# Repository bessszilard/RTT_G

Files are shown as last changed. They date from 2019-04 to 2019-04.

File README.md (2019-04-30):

# RTT_G
## The Autonomous Sign Detector and Object Tracker Robot

*Keywords: differential drive robot, real-time image processing, GUI, Arduino, PCB design, motor control.*

The project includes the construction of a robot with differential drive, itsʼ control mechanism and machine vision based guidance. The robot is controlled by an ATmega2560 microcontroller on an Arduino development board. Itsʼ structure also contains the following elements: sensor-electronics, two DC motors, two accumulators, one servo motor, vision system with active illumination and one Bluetooth module. A proprietary interface card connects the microcontroller with the sensors and the interveners.
The strategic level guidance is accomplished with an application running on PC based architecture. The PC and the robot communicate with each other via Bluetooth. The robot can work in two modes: first one is the manual control mode, the second one is the autonomous mode.
First program is the manually operated mode, in which the user can guide the robot using the PCʼs keyboard. The second program implements autonomous guidance. In this mode, PC controls the robot based on the result of processing a video feed from a mobile phone mounted onto the robot. Image processing is performed on the PC using Emgu CV which is based on the OpenCV libraries.

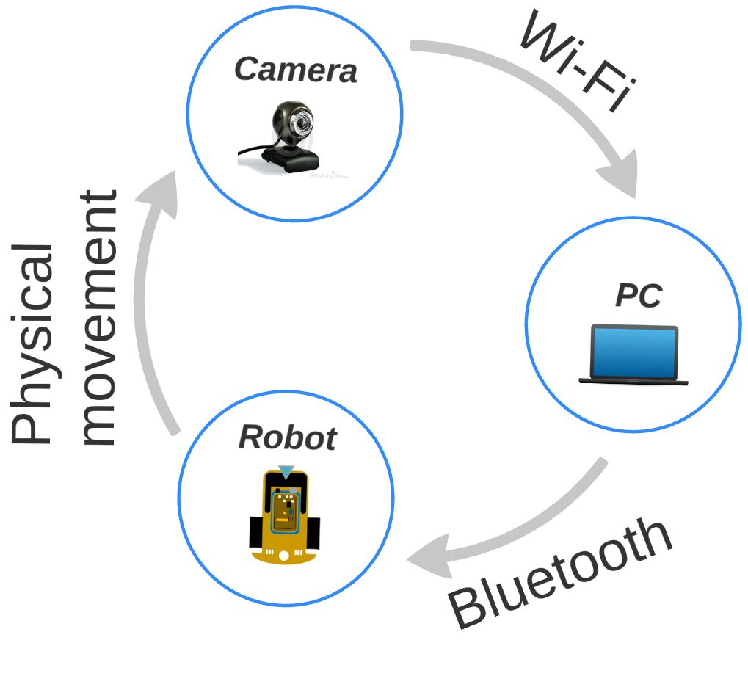
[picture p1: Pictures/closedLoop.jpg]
Closed loop control Title


https://www.youtube.com/watch?v=aYvZUBr8wPQ

## Installing Arduino IDE
* [Windows install](https://www.arduino.cc/en/guide/windows)
* [Linux](https://www.arduino.cc/en/guide/linux)
* [MAC](https://www.dummies.com/computers/arduino/how-to-install-arduino-for-mac-os-x/)

## Arduino projects
* R_TTG_IMG_Proc_9_Serial - Robot is controlled with a Machine Vision program
* R_TTG_Timers_Encoder_test_PID_4 - Robot is controlled with keyboard

## License
MIT License

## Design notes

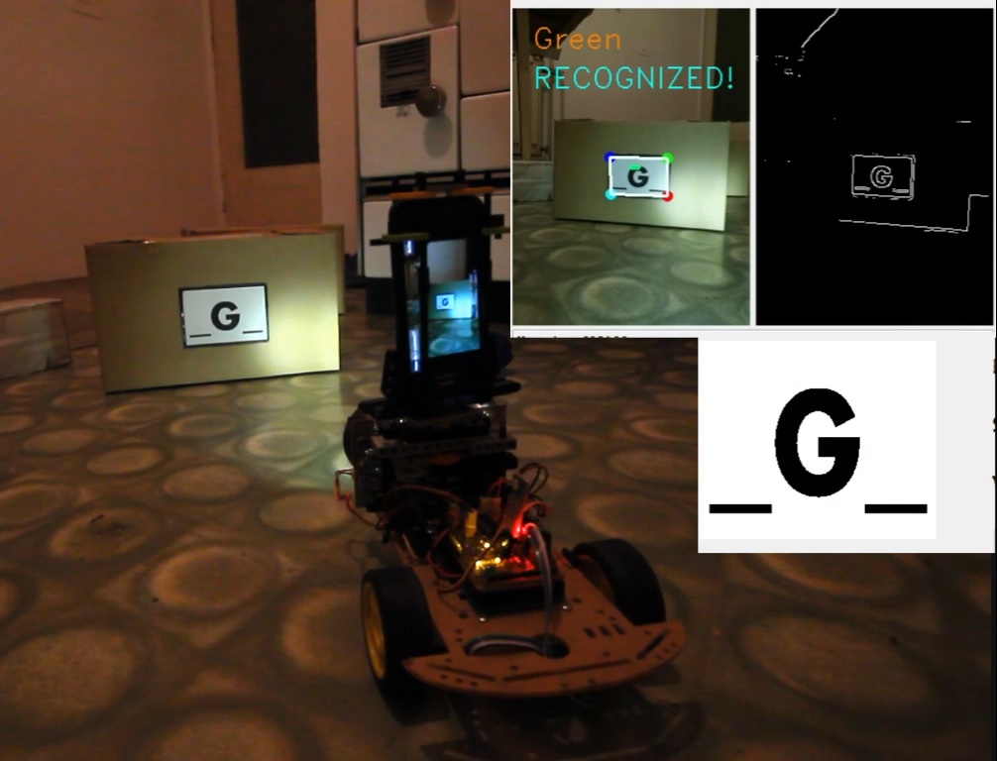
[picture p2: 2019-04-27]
Pictures/Sign_detection2.jpg

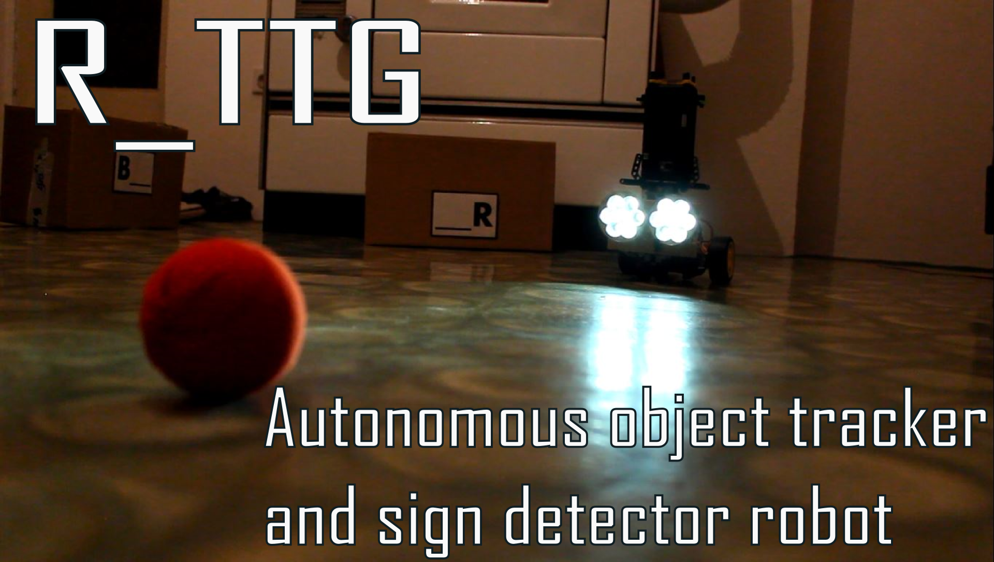
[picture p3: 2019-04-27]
Pictures/cover_photo.jpg.png

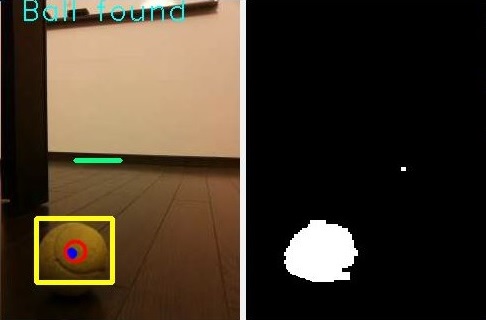
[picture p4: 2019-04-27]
Pictures/Ball_Found.jpg

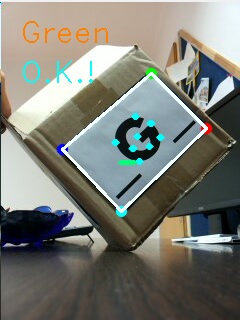
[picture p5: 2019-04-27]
Pictures/perspektiv_korrekcio_eredeti.jpg

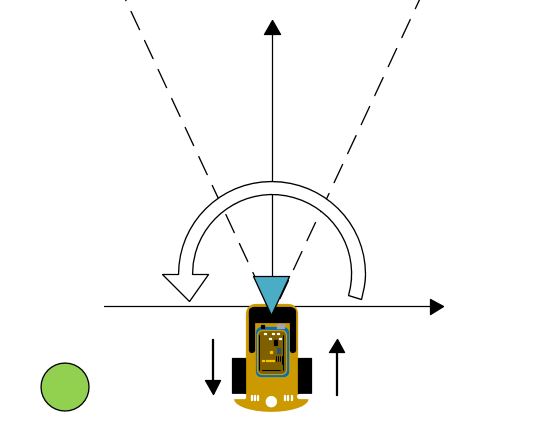
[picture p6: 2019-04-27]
Pictures/searching_mode.JPG

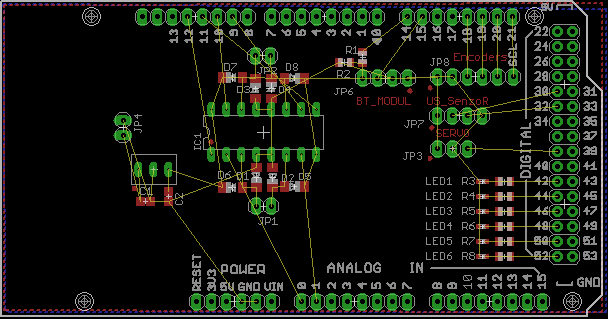
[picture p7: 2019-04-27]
arduino_Eagle_PCB/PCB.png

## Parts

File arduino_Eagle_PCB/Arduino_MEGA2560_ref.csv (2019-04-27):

Part | Value | Device | Package | Description | MF | MPN | OC_FARNELL | OC_NEWARK
ADCH |  | PINHD-1X8 | 1X08 | PIN HEADER
ADCL |  | PINHD-1X8 | 1X08 | PIN HEADER
C1 |  | C-USC0805 | C0805 | CAPACITOR, American symbol
C2 |  | C-USC0805 | C0805 | CAPACITOR, American symbol
COMMUNICATION |  | PINHD-1X8 | 1X08 | PIN HEADER
D1 | PMLL4150 | PMLL4150 | SOD80C | DIODE
D2 | PMLL4150 | PMLL4150 | SOD80C | DIODE
D3 | PMLL4150 | PMLL4150 | SOD80C | DIODE
D4 | PMLL4150 | PMLL4150 | SOD80C | DIODE
D5 | PMLL4150 | PMLL4150 | SOD80C | DIODE
D6 | PMLL4150 | PMLL4150 | SOD80C | DIODE
D7 | PMLL4150 | PMLL4150 | SOD80C | DIODE
D8 | PMLL4150 | PMLL4150 | SOD80C | DIODE
IC1 | L293D | L293D | DIL16 | PUSH-PULL 4 CHANNEL DRIVER |  | L293D | 9589619 | 56P8249
JP1 |  | PINHD-1X2 | 1X02 | PIN HEADER
JP2 |  | PINHD-1X2 | 1X02 | PIN HEADER
JP3 | SERVO | PINHD-1X3 | 1X03 | PIN HEADER
JP4 |  | PINHD-1X2 | 1X02 | PIN HEADER
JP6 | BLUETOOTH_MODUL | PINHD-1X4 | 1X04 | PIN HEADER
JP7 | UltraSonic_SenzoR | PINHD-1X4 | 1X04 | PIN HEADER
JP8 | ENCODERS | PINHD-1X6 | 1X06 | PIN HEADER
LED1 |  | LED | SMARTLED-TTW | LED
LED2 |  | LED | SMARTLED-TTW | LED
LED3 |  | LED | SMARTLED-TTW | LED
LED4 |  | LED | SMARTLED-TTW | LED
LED5 |  | LED | SMARTLED-TTW | LED
LED6 |  | LED | SMARTLED-TTW | LED
POWER |  | PINHD-1X6 | 1X06 | PIN HEADER
PWMH |  | PINHD-1X8 | 1X08 | PIN HEADER
PWML |  | PINHD-1X8 | 1X08 | PIN HEADER
R1 | 10k | R-US_R0805 | R0805 | RESISTOR, American symbol
R2 | 20k | R-US_R0805 | R0805 | RESISTOR, American symbol
R3 | 350 | R-US_R0805 | R0805 | RESISTOR, American symbol
R4 | 350 | R-US_R0805 | R0805 | RESISTOR, American symbol
R5 | 350 | R-US_R0805 | R0805 | RESISTOR, American symbol
R6 | 350 | R-US_R0805 | R0805 | RESISTOR, American symbol
R7 | 350 | R-US_R0805 | R0805 | RESISTOR, American symbol
R8 | 350 | R-US_R0805 | R0805 | RESISTOR, American symbol
U$1 | 7805 | 7805 | TO-220
XIOH |  | PINHD-2X8 | 2X08 | PIN HEADER
XIOL |  | PINHD-2X8 | 2X08 | PIN HEADER

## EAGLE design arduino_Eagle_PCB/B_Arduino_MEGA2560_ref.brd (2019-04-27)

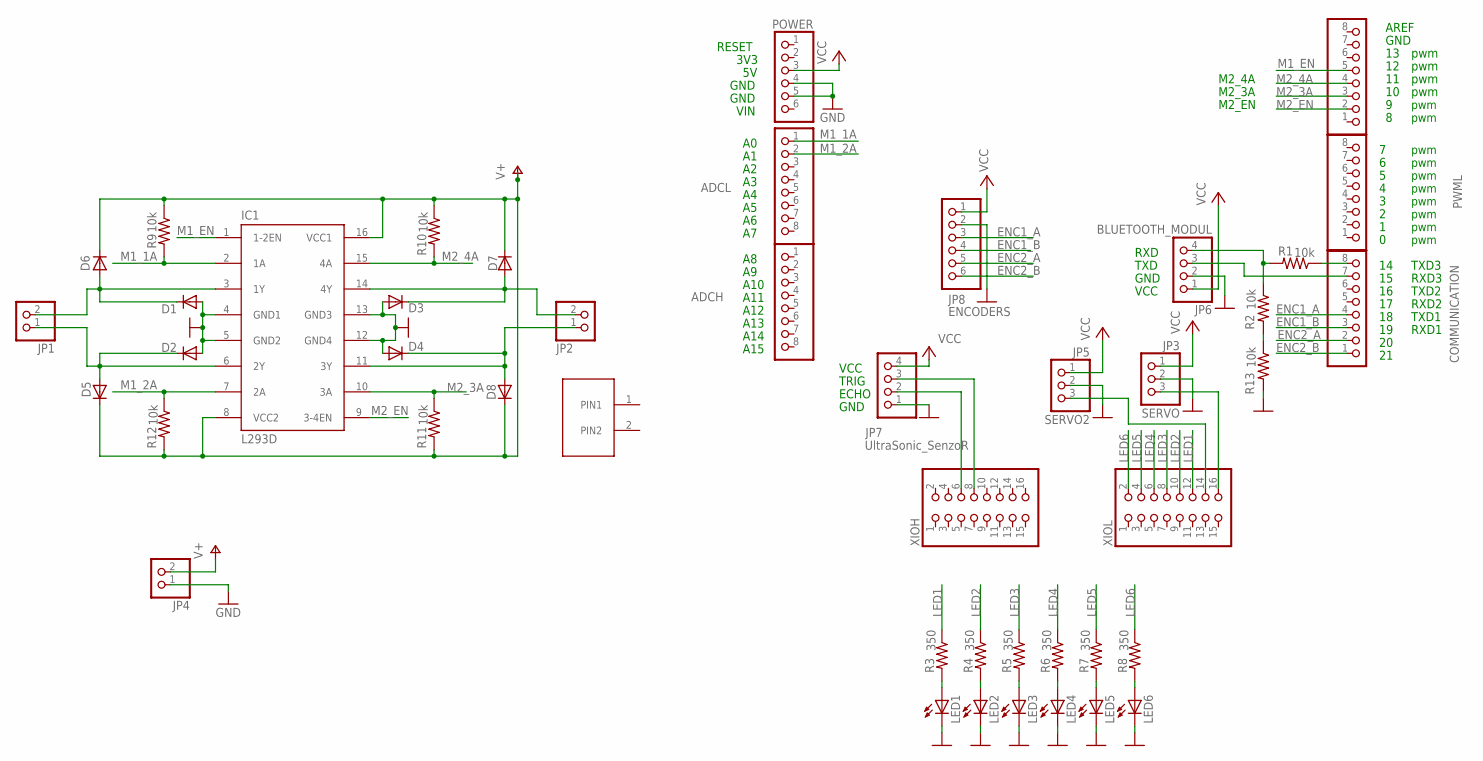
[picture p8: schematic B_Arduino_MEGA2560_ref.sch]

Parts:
ADCH: PINHD-1X8; 1X08
ADCL: PINHD-1X8; 1X08
COMMUNICATION: PINHD-1X8; 1X08
D1, D2, D3, D4, D5, D6, D7, D8: PMLL4150; SOD80C
IC1: L293D; DIL16
JP1, JP2, JP4: PINHD-1X2; 1X02
JP3: SERVO; 1X03
JP5: SERVO2; 1X03
JP6: BLUETOOTH_MODUL; 1X04
JP7: UltraSonic_SenzoR; 1X04
JP8: ENCODERS; 1X06
LED1, LED2, LED3, LED4, LED5, LED6: LED; SMARTLED-TTW
POWER: PINHD-1X6; 1X06
PWMH: PINHD-1X8; 1X08
PWML: PINHD-1X8; 1X08
R1, R2, R9, R10, R11, R12, R13: 10k; R0805
R3, R4, R5, R6, R7, R8: 350; R0805
U$1: FR_L_PNHD_2; FR_L_PN_HD-2
XIOH: PINHD-2X8; 2X08
XIOL: PINHD-2X8; 2X08

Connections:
ENC1_A: COMMUNICATION.4, JP8.3
ENC1_B: COMMUNICATION.3, JP8.4
ENC2_A: COMMUNICATION.2, JP8.5
ENC2_B: COMMUNICATION.1, JP8.6
GND: D1.A, D2.A, D3.A, D4.A, IC1.4 (GND1), IC1.5 (GND2), IC1.12 (GND4), IC1.13 (GND3), JP3.2, JP4.1, JP5.2, JP6.2, JP7.1, JP8.2, LED1.C@1 (C), LED2.C@1 (C), LED3.C@1 (C), LED4.C@1 (C), LED5.C@1 (C), LED6.C@1 (C), POWER.4, POWER.5, R13.2
LED1: R3.1, XIOL.12
LED2: R4.1, XIOL.10
LED3: R5.1, XIOL.8
LED4: R6.1, XIOL.6
LED5: R7.1, XIOL.4
LED6: R8.1, XIOL.2
M1_1A: ADCL.1, IC1.2 (1A), R9.2
M1_2A: ADCL.2, IC1.7 (2A), R12.1
M1_EN: IC1.1 (1-2EN), PWMH.5
M2_3A: IC1.10 (3A), PWMH.3, R11.1
M2_4A: IC1.15 (4A), PWMH.4, R10.2
M2_EN: IC1.9 (3-4EN), PWMH.2
unnamed: D1.C, D6.A, IC1.3 (1Y), JP1.2
unnamed: D2.C, D5.A, IC1.6 (2Y), JP1.1
unnamed: D3.C, D7.A, IC1.14 (4Y), JP2.2
unnamed: D4.C, D8.A, IC1.11 (3Y), JP2.1
unnamed: JP3.3, XIOL.16
unnamed: COMMUNICATION.7, JP6.3
unnamed: COMMUNICATION.8, R1.1
unnamed: JP6.4, R1.2, R2.1
unnamed: R2.2, R13.1
unnamed: JP7.3, XIOH.8
unnamed: JP7.2, XIOH.6
unnamed: LED1.A@1 (A), R3.2
unnamed: LED2.A@1 (A), R4.2
unnamed: LED3.A@1 (A), R5.2
unnamed: LED4.A@1 (A), R6.2
unnamed: LED5.A@1 (A), R7.2
unnamed: LED6.A@1 (A), R8.2
unnamed: JP5.3, XIOL.14
V+: D5.C, D6.C, D7.C, D8.C, IC1.8 (VCC2), IC1.16 (VCC1), JP4.2, R9.1, R10.1, R11.2, R12.2
VCC: JP3.1, JP5.1, JP6.1, JP7.4, JP8.1, POWER.3

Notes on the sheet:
pwm
GND
AREF
A10
A11
A12
A13
A14
A15
RESET
3V3
VIN
TXD3
RXD3
TXD2
RXD2
TXD1
RXD1
VCC
TXD
RXD
TRIG
ECHO
M2_EN
M2_4A
M2_3A

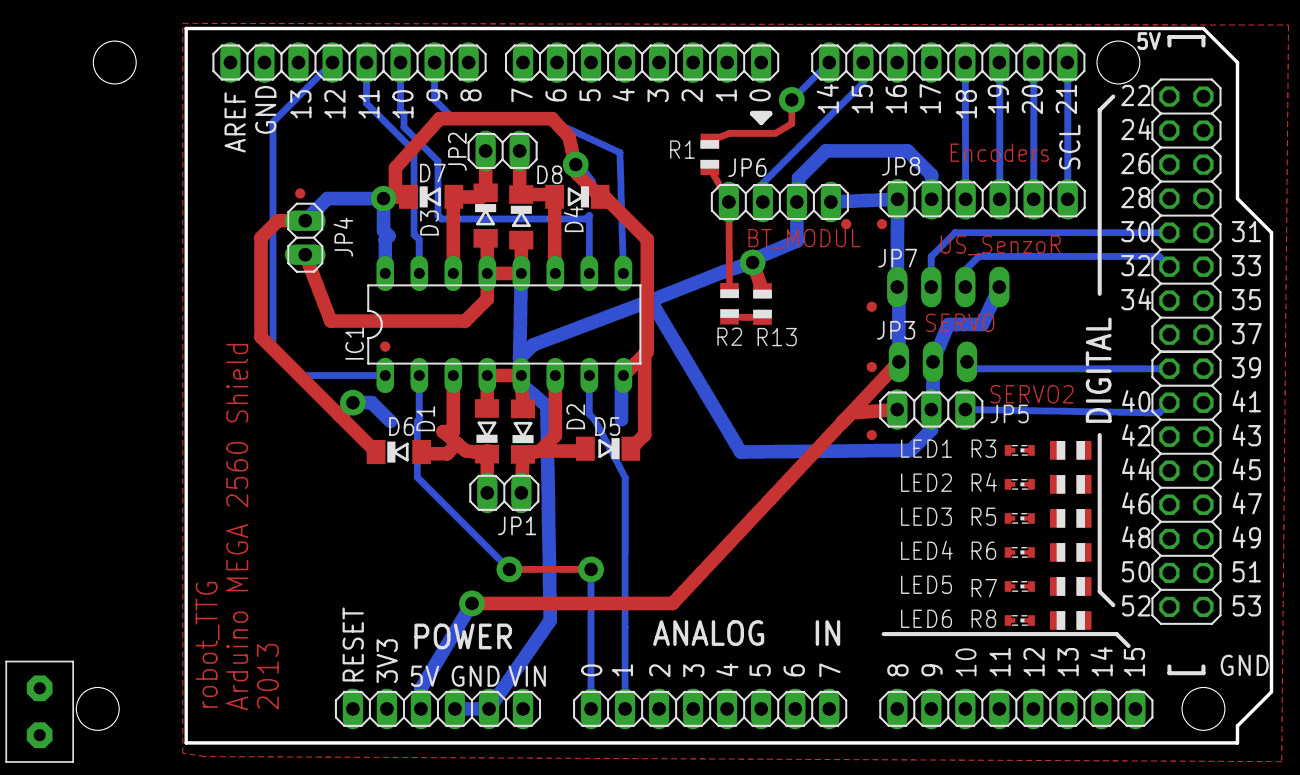
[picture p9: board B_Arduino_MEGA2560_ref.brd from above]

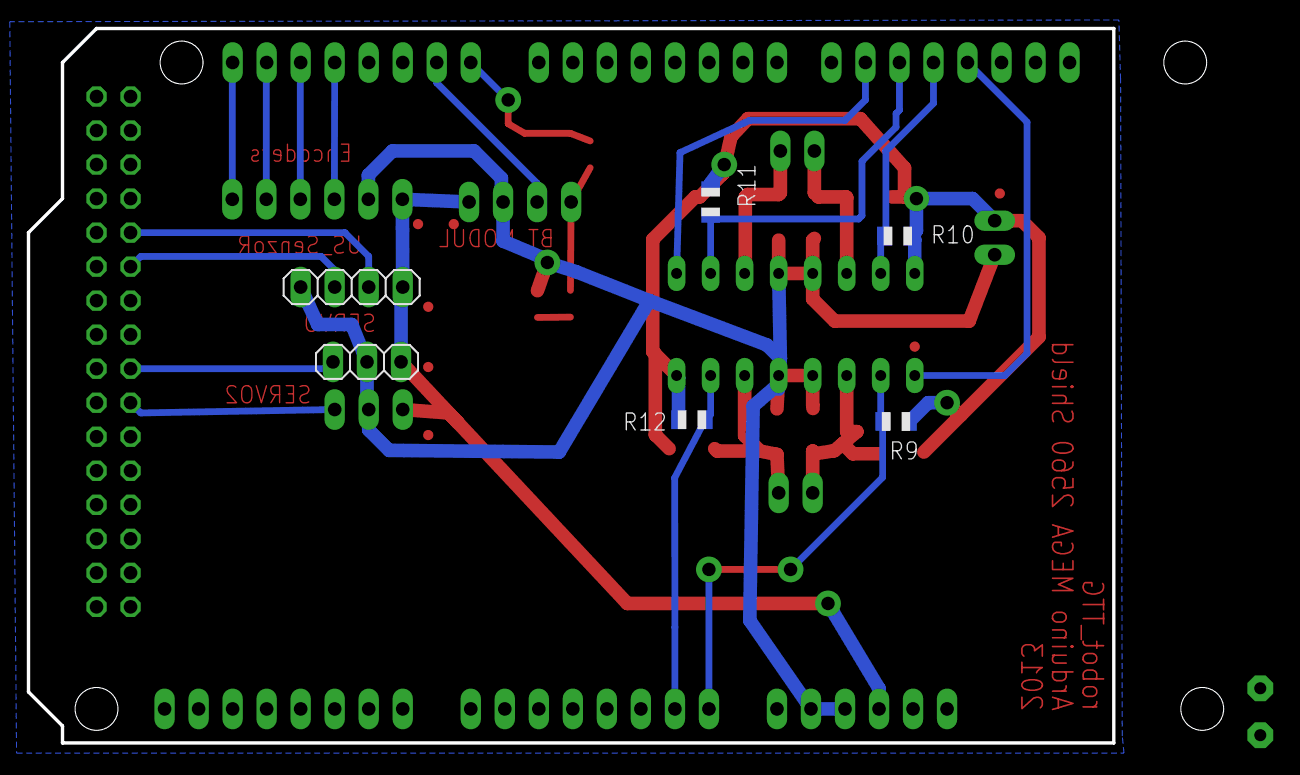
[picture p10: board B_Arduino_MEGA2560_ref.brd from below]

Board: 2 copper layers, 81.0 x 53.3 mm, 45 parts (6 on the bottom side), 37 nets.

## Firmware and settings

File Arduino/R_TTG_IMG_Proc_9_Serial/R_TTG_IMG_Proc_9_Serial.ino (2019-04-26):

  #include "init_header.h"
  #include <WProgram.h>
  #include <Servo.h>
  #include <avr/wdt.h>
  
  unsigned int timer0_counter = 0;
  unsigned int timer3_counter = 0;
  unsigned int timer4_counter = 0;
  
  unsigned int i = 0;
  unsigned int j = 0;
  
  unsigned char L_Motor_dir = 0;
  unsigned char R_Motor_dir = 0;
  int  L_Motor_Pos = 0;
  int  R_Motor_Pos = 0;
  
  int l_enc = 0;
  unsigned int l_enc_temp;
  int r_enc = 0;
  unsigned int r_enc_temp;
  
  // bool timer0_flag2 = 0;
  bool timer3_flag = 0;
  bool timer4_flag = 0;
  
  bool moving_flag = 0;
  int Kp = 3;
  int Kpper = 1;    // never be 0 
  int Kpi = 200;// 2;
  int Kpiper = 2;    // never be 0
  int Ki = 0;
  int Kiper = 150;    // never be 0
  
  int Kp_Acc = 0;//1;
  int Kpper_Acc = 100;
  
  int stab_imp = 2;
  int curve = 0;
  
  int Kp_curve = 1;
  int Kpper_curve = 2;
  
  int I_error = 0;
  int IAcc_error = 0;
  int PI_error;
  int Acc_error;
  
  int Left_Motor_PWM = 0;
  int Right_Motor_PWM = 0;
  unsigned int l_motor_interrupts;
  unsigned int r_motor_interrupts;
  unsigned int l_temp;
  unsigned int r_temp;
  
  // servo  
  Servo servo38;
  int pos = 90;
  int def_pos = 95;
  bool Go_flag = 0;
  bool start_search_flag = 1;
  
  // turining
  int  pos_L = 0;
  int  pos_L_temp = 1;
  int  pos_L_rot = 65;          // how much impuls
  unsigned int rot_counter = 0;
  
  bool rotate_complete = false;
  
  // lighting
  unsigned int lighting_PWM;
  
  // fucntiions
  void Left_Motor_(unsigned int dir);
  void Right_Motor_(unsigned int dir);
  void Command_S(unsigned int inByte);
  
  void setup() {
    wdt_enable(WDTO_4S);
  
    LED_Init();
    Encoder_Init();
    Motor_Init();
    Lamp_Init();
    attachInterrupt(5, LA_interrupt, CHANGE);  // Pin 18
    attachInterrupt(4, RA_interrupt, CHANGE);  // Pin 19
  
    Serial.begin (9600);
    Serial3.begin(9600);
  
    servo38.attach(38);
  
    pos = def_pos;
    servo38.write(pos);
  
    noInterrupts();           // disable all interrupts
    // sampling encoders interrupts
    // PID control
    timer4_Init(64);         // timer4(prescaler); 8, 64, 256, 1024
    timer4_counter = 53035;  // 20 Hz
  
    // 64 40535 10  Hz 
    // 64 53035 20  Hz
    // 64 63035 100 Hz
    // sampling accalerometer
    interrupts();            // enable all interrupts  
  }
  //////////////////////////Loop//////////////////////////
  void loop() {
    if(Serial3.available()) {
      unsigned int inByte = Serial3.read();
      Command_S(inByte);
    }    
    wdt_reset(); 
  }////////////////////////Loop End///////////////////////
  
  bool LA;
  bool LB;
  ////////////////////////Interrupts/////////////////////
  //Input Change Noticed
  void LA_interrupt() {
    LA = digitalRead(Enc_LA);
    LB = digitalRead(Enc_LB);
  
    /* if(LA)
     if(LB) L_Motor_dir = FOWARD;
     else   L_Motor_dir = BACKWARD;
     else
     if(LB) L_Motor_dir = BACKWARD; 
     else   L_Motor_dir = FOWARD;
     */
  
    if(LA)
      if(LB) pos_L += 1;
      else   pos_L -= 1;
    else
      if(LB) pos_L -= 1; 
      else   pos_L += 1;
    l_enc += 1;
  
    //  TCNT3 = timer3_counter;      // moving
  }
  
  bool RA;
  bool RB;
  void RA_interrupt() {
    /*  RA = digitalRead(Enc_RA);
     RB = digitalRead(Enc_RB);
     
     if(RA)
     if(RB) R_Motor_dir = FOWARD;
     else   R_Motor_dir = BACKWARD;
     else
     if(RB) R_Motor_dir = BACKWARD;
     else   R_Motor_dir = FOWARD;
     */
    r_enc += 1;
    //   TCNT3 = timer3_counter;    // moving
  }

  ISR(TIMER4_OVF_vect) {  // L_Motor timer
  
    TCNT4 = timer4_counter;   // preload timer
    if(moving_flag) {
      digitalWrite(LED42, HIGH);
      l_motor_interrupts = l_enc;
      r_motor_interrupts = r_enc;
  
  
  
      PI_error = ((int)l_enc  - (int)r_enc);
      I_error += ((int)l_enc  - (int)r_enc);
      //  II_error += I_error;
  
      Left_Motor_PWM  += Kp * (stab_imp - l_enc - Kpi * PI_error / Kiper) + curve;//*/ - Ki * I_error / Kiper) / Kpper;
      Right_Motor_PWM += Kp * (stab_imp - r_enc + Kpi * PI_error / Kiper) - curve;//*/ + Ki * I_error / Kiper) / Kpper;
  
      //      Left_Motor_PWM = 200;
      //      Right_Motor_PWM = 200;
  
      if(Left_Motor_PWM  > 255) Left_Motor_PWM = 255;
      if(Right_Motor_PWM > 255) Right_Motor_PWM = 255;
      if(Left_Motor_PWM  < 0)  Left_Motor_PWM = 0;
      if(Right_Motor_PWM < 0)  Right_Motor_PWM = 0;
  
      analogWrite(Left_Motor_PWM_Pin, Left_Motor_PWM);
      analogWrite(Right_Motor_PWM_Pin, Right_Motor_PWM);
  
  
    }
    l_enc = 0;
    r_enc = 0;
    timer4_flag = 1;
  }
  /*
                          void serialEvent3() {
   inByte = Serial3.read();
   Command_S();
   }
   */
  ////////////////////////Interrupts/////////////////////
  //////////////////// Other_unctions///////////////////
  void Right_Motor_(unsigned int dir) {
    switch(dir) {
    case FOWARD:
      digitalWrite(Right_Motor_1A, HIGH);
      digitalWrite(Right_Motor_2A, LOW); 
      break;
    case BACKWARD:
      digitalWrite(Right_Motor_1A, LOW);
      digitalWrite(Right_Motor_2A, HIGH);
      break;
    case STOP:
      digitalWrite(Right_Motor_1A, LOW);
      digitalWrite(Right_Motor_2A, LOW);
      break;
    }
  }
  
  void Left_Motor_(unsigned int dir) {
    switch(dir) {
    case FOWARD:
      digitalWrite(Left_Motor_3A, HIGH);
      digitalWrite(Left_Motor_4A, LOW); 
      break;
    case BACKWARD:
      digitalWrite(Left_Motor_3A, LOW);
      digitalWrite(Left_Motor_4A, HIGH);
      break;
    case STOP:
      digitalWrite(Left_Motor_3A, LOW);
      digitalWrite(Left_Motor_4A, LOW);
      break;
    }
  }
  
  void Command_S(unsigned int inByte) {
    if(moving_flag == 0) {     // robot is not moving
      Left_Motor_PWM  = 0;
      Right_Motor_PWM = 0;
      curve = 0;
      stab_imp = 5;
    }
    if(Serial3.available() && inByte != 'R') {
      start_search_flag = true;
      rot_counter = 0;
      digitalWrite(LED52,!digitalRead(LED52));
    }
    if(inByte == 'W') {        // go foward
      Left_Motor_(FOWARD);
      Right_Motor_(FOWARD);
      moving_flag = 1;
      curve = 0;
      stab_imp = 5;  
      //      Robot(GO,FOWARD,STRAIGHT,5);
    }
    else if(inByte == 'S') {  // go backward
      Left_Motor_(BACKWARD);
      Right_Motor_(BACKWARD);
      moving_flag = 1;
      curve = 0;
      stab_imp = 5;
    }
    else if(inByte == 'A') {  // turn left
      Left_Motor_(BACKWARD);
      Right_Motor_(FOWARD);
      moving_flag = 1;
      curve = 0;
      stab_imp = 5;
    }
    else if(inByte == 'D') {  // turn right
      Left_Motor_(FOWARD);
      Right_Motor_(BACKWARD);
      moving_flag = 1;
      curve = 0;
      stab_imp = 5;
    }
    else if(inByte == 'H') {  // stop moving
      Left_Motor_ (STOP);
      Right_Motor_(STOP);
  
      moving_flag = 0;
  
      if(l_enc !=0 && r_enc !=0) {  
        Left_Motor_PWM = 0;
        Right_Motor_PWM = 0;
        IAcc_error = 0;
        I_error  = 0;
      } 
    }
    else if(inByte == 'h') {  // stop moving and than correct position
      if(abs(pos - def_pos) <= 5) {
        LEDS(BLINK);
        moving_flag = 0;
      }
      else if(pos - def_pos > 5) {       // robot have to turn right    
        Left_Motor_(FOWARD);       // 'D'
        Right_Motor_(BACKWARD);
        moving_flag = 1;
        stab_imp = 2;
        curve = 0;
  
        if(pos > 100)  delay(30);  // faster
        else           delay(10);
      }
      else if(pos - def_pos < -5) { // robot have to turn left    
        Left_Motor_(BACKWARD);     // 'A'
        Right_Motor_(FOWARD);
        moving_flag = 1;
  
        stab_imp = 2;
        curve = 0;
        if(pos < 80)  delay(30);  // faster
        else          delay(10);  
      }   
      Left_Motor_ (STOP);
      Right_Motor_(STOP);
      //    moving_flag = 0;
    }
  
    else if(inByte == 'e') {  // servo fast turn right
      pos -= 2;              // fast right turn
      if(pos < 0) pos = 0;
      servo38.write(pos);
  
      Left_Motor_PWM  = 100;
      Right_Motor_PWM = 100;
      /*      moving_flag = 0;
       Left_Motor_ (STOP);
       Right_Motor_(STOP);  
       */  }
    else if(inByte == 'd') {  // servo turn right
      pos -= 1;              // right turn
      if(pos < 0) pos = 0;
      servo38.write(pos);
  
      Left_Motor_PWM  = 100;
      Right_Motor_PWM = 100;
  
      /*      moving_flag = 0;
       Left_Motor_ (STOP);
       Right_Motor_(STOP);  
       */  }
    else if(inByte == 'q') { // servo fast turn left
      pos += 2;             // fast left turn
      if(pos > 180) pos = 180;
      servo38.write(pos);
      //     moving_flag = 0;
  
      Left_Motor_PWM  = 100;
      Right_Motor_PWM = 100;
      //      Left_Motor_ (STOP);
      //      Right_Motor_(STOP);  
    }
    else if(inByte == 'a') { // servo turn left
      pos += 1;             // left turn
      if(pos > 180) pos = 180;
      servo38.write(pos);
  
      Left_Motor_PWM  = 100;
      Right_Motor_PWM = 100;
    }
    else if(inByte == 'o') {        // ball found - positing robot << >>
      if(pos - def_pos > 1) {       // robot have to turn right    
        Left_Motor_(FOWARD);       // 'D'
        Right_Motor_(BACKWARD);
        moving_flag = 1;
        stab_imp = 2;
        curve = 0;
  
        if(pos > 100)  delay(30);  // faster
        else           delay(10);
      }
      else if(pos - def_pos < -1) { // robot have to turn left    
        Left_Motor_(BACKWARD);     // 'A'
        Right_Motor_(FOWARD);
        moving_flag = 1;
  
        stab_imp = 2;
        curve = 0;
        if(pos < 80)  delay(30);  // faster
        else          delay(10);  
      }   
      Left_Motor_ (STOP);
      Right_Motor_(STOP);
      moving_flag = 0;
    }
    else if(inByte == '1' || inByte == '2' || inByte == '3') {  // ball found
      if(def_pos - 1 <= pos && pos <= def_pos + 1) { // robot is in ball direction, goind foward
        if      (inByte == '1') stab_imp = 1;       // speed_1
        else if (inByte == '2') stab_imp = 2;       // speed_2
        else if (inByte == '3') stab_imp = 3;       // speed_3
  
          Left_Motor_(FOWARD);
        Right_Motor_(FOWARD);
        moving_flag = 1;
        curve = 0;
      }
      else if(pos - def_pos > 1) {                   // robot have to turn right    
        Left_Motor_(FOWARD);  // 'D'
        Right_Motor_(BACKWARD);
        curve = 0;
        moving_flag = 1;
        stab_imp = 2;
  
        if(pos > 100)  delay(60);
        else  delay(20);
        Left_Motor_ (STOP);
        Right_Motor_(STOP);
      }
      else if(pos - def_pos < -1) {                 // robot have to turn left    
        Left_Motor_(BACKWARD);  // 'A'
        Right_Motor_(FOWARD);
        curve = 0;
        moving_flag = 1;
        stab_imp = 2;
  
        if(pos < 80)  delay(60);
        else  delay(20);  
        Left_Motor_ (STOP);
        Right_Motor_(STOP);  
      }   
    }
    else if(inByte == 'O') {                        // curve
      Left_Motor_(FOWARD);
      Right_Motor_(FOWARD);
  
      curve = Kp_curve * (pos - def_pos) / Kpper_curve;
      stab_imp = 2;
      moving_flag = 1;
  
      if(pos - def_pos > 45) {
        Left_Motor_(FOWARD);  // 'D'
        Right_Motor_(STOP);
      }
      if(pos - def_pos < -45) {
        Left_Motor_(STOP);  // 'D'BACKWARD
        Right_Motor_(FOWARD);
      }
    }
    else if(inByte == 'R') {  // searching for the ball
      //if(timer3_flag) {
        pos = def_pos;
        servo38.write(def_pos);
        Left_Motor_(BACKWARD);  // 'A'
        Right_Motor_(FOWARD);
        curve = 0;
        moving_flag = 1;
        stab_imp = 2;
  
        delay(45);  
        Left_Motor_ (STOP);
        Right_Motor_(STOP);  
    //  }
    }
    else if(inByte == 0) analogWrite(Lamp_Pin, 0); 
    else if(inByte == 1) analogWrite(Lamp_Pin, 25); 
    else if(inByte == 2) analogWrite(Lamp_Pin, 255 - 7*25); 
    else if(inByte == 3) analogWrite(Lamp_Pin, 255 - 6*25); 
    else if(inByte == 4) analogWrite(Lamp_Pin, 255 - 5*25); 
    else if(inByte == 5) analogWrite(Lamp_Pin, 255 - 4*25); 
    else if(inByte == 6) analogWrite(Lamp_Pin, 255 - 3*25); 
    else if(inByte == 7) analogWrite(Lamp_Pin, 255 - 2*25); 
    else if(inByte == 8) analogWrite(Lamp_Pin, 255 - 1*25); 
    else if(inByte == 9) analogWrite(Lamp_Pin, 255); 
  
//    analogWrite(Lamp_Pin, 255);
  }
  
  
  

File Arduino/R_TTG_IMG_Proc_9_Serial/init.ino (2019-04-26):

  //#include <Arduino.h>
  #include "init_header.h"
  #include <WProgram.h>
  
  void Accelero_Init(){
    pinMode(Acc_X_Pin, INPUT);
    pinMode(Acc_Y_Pin, INPUT);
    pinMode(Acc_Z_Pin, INPUT);
    analogReference(INTERNAL2V56);  
  }
  
  void Encoder_Init(){
    pinMode(Enc_RA, INPUT);
    pinMode(Enc_RB, INPUT);
    pinMode(Enc_LA, INPUT);
    pinMode(Enc_LB, INPUT); 
  }
  
  void Motor_Init(){
    pinMode(Left_Motor_PWM_Pin, OUTPUT);
    pinMode(Left_Motor_4A,  OUTPUT);
    pinMode(Left_Motor_3A,  OUTPUT);
  
    pinMode(Right_Motor_PWM_Pin, OUTPUT);  
    pinMode(Right_Motor_1A,  OUTPUT);  
    pinMode(Right_Motor_2A,  OUTPUT); 
  }
  
  void LED_Init(){
    pinMode(LED42, OUTPUT);
    pinMode(LED44, OUTPUT);
    pinMode(LED46, OUTPUT);
    pinMode(LED48, OUTPUT);
    pinMode(LED50, OUTPUT);
    pinMode(LED52, OUTPUT);
  
    digitalWrite(LED42, LOW);
    digitalWrite(LED44, LOW);
    digitalWrite(LED46, LOW);
    digitalWrite(LED48, LOW);
    digitalWrite(LED50, LOW);
    digitalWrite(LED52, LOW);
  }
  void Lamp_Init(){
    pinMode(Lamp_Pin, OUTPUT);
  }  

  void timer3_Init(unsigned int prescaler){
    TCCR3A = 0;
    TCCR3B = 0;
  
    TCNT3 = timer3_counter;   // preload timer
    switch(prescaler){
    case 1:    // 1 prescaler
      TCCR3B |= (1 << CS10);
      break;
    case 8:    // 8 prescaler
      TCCR3B |= (1 << CS11);
      break;
    case 64:   // 64 prescaler 
      TCCR3B |= (1 << CS10);
      TCCR3B |= (1 << CS11);    
      break;
    case 256:  // 256 prescaler 
      TCCR3B |= (1 << CS12);    
      break;
    case 1024: // 64 prescaler 
      TCCR3B |= (1 << CS10);
      TCCR3B |= (1 << CS12);    
      break;
    default:   // 1 prescaler
      TCCR3B |= (1 << CS10);
      break;
    }
    TIMSK3 |= (1 << TOIE1);   // enable timer overflow interrupt
  }
  
  void timer4_Init(unsigned int prescaler){
    TCCR4A = 0;
    TCCR4B = 0;
    TCNT4 = timer4_counter;   // preload timer
    switch(prescaler){
    case 1: // 1 prescaler
      TCCR4B |= (1 << CS10);
      break;
    case 8:  // 8 prescaler
      TCCR4B |= (1 << CS11);
      break;
    case 64: // 64 prescaler 
      TCCR4B |= (1 << CS10);
      TCCR4B |= (1 << CS11);    
      break;
    case 256: // 256 prescaler 
      TCCR4B |= (1 << CS12);    
      break;
    case 1024: // 64 prescaler 
      TCCR4B |= (1 << CS10);
      TCCR4B |= (1 << CS12);    
      break;
    default:  // 1 prescaler
      TCCR4B |= (1 << CS10);
      break;
    }
    TIMSK4 |= (1 << TOIE1);   // enable timer overflow interrupt
  }
  
  void LEDS(unsigned int STATUS){
    switch(STATUS){
    case OFF:
      digitalWrite(LED42, LOW);
      digitalWrite(LED44, LOW);
      digitalWrite(LED46, LOW);
      digitalWrite(LED48, LOW);
      digitalWrite(LED50, LOW);
      digitalWrite(LED52, LOW);
      break;
    case ON:
      digitalWrite(LED42, HIGH);
      digitalWrite(LED44, HIGH);
      digitalWrite(LED46, HIGH);
      digitalWrite(LED48, HIGH);
      digitalWrite(LED50, HIGH);
      digitalWrite(LED52, HIGH);
      break;
    case BLINK:
      digitalWrite(LED42, !digitalRead(LED42));
      digitalWrite(LED44, !digitalRead(LED44));
      digitalWrite(LED46, !digitalRead(LED46));
      digitalWrite(LED48, !digitalRead(LED48));
      digitalWrite(LED50, !digitalRead(LED50));
      digitalWrite(LED52, !digitalRead(LED52));
      break;
    }
  }
  
  

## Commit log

2019-04-26 Arduino projects added
    Robot is controlled by Machine Vision algorithm in R_TTG_IM_Proc_9 .
    Robot is controlled manualle via Keyboard in R_TTG_Timers_Encoder_test_PID_4 project
    These projects were created in 2014
2019-04-27 PCB and pictures added
    Added Eagle files and pictures
    [Arduino_MEGA2560_ref.brd, Arduino_MEGA2560_ref.csv, Arduino_MEGA2560_ref.sch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]
2019-04-30 Added install description and additional info
    Update: Descriptions and closed loop added to README.md file
    Added Installation description, Closed loop control picture, Arduino project descriptions, and License description.
